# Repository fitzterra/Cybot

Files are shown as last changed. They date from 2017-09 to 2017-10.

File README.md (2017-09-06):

Cybot Resurrected
=================

**Table of Contents**
1. [Features](#features)
2. [Hardware and Electronics](#hardware-and-electronics)
3. [Software](#software)

----

This is a project to bring my old [Cybot] back my to life.

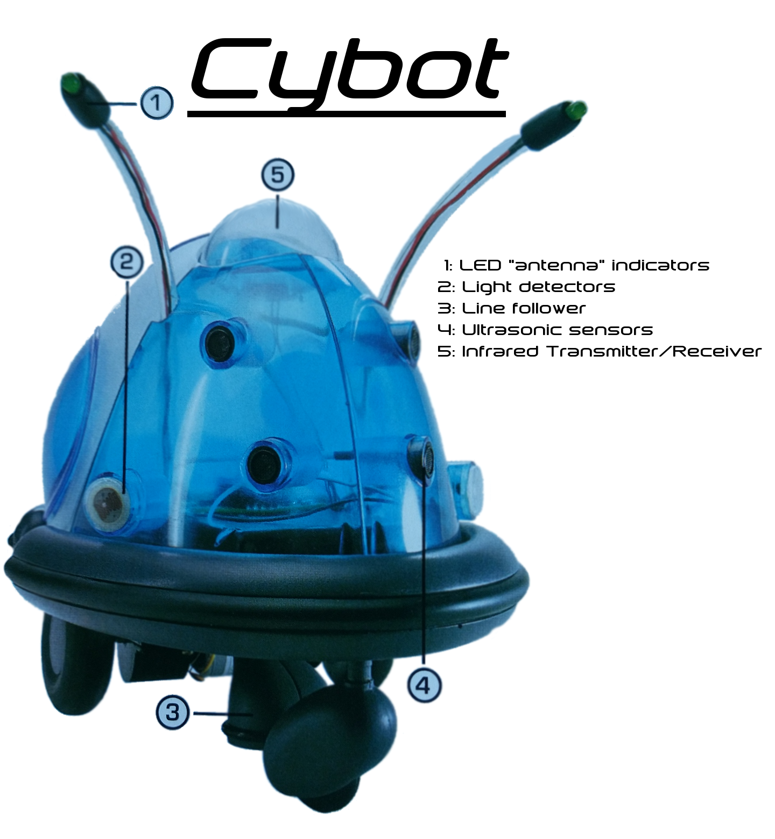
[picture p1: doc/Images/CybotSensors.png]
Cybot Sensors

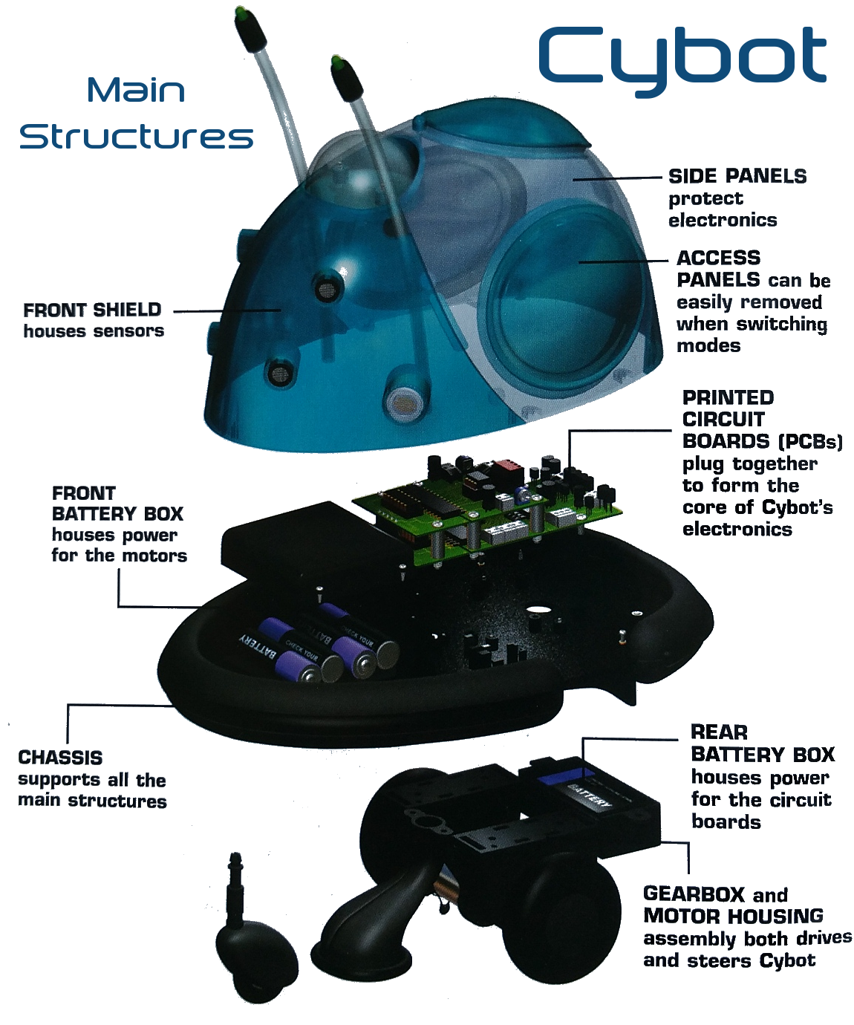
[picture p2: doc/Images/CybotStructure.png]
Cybot Structure


After I lost my remote control (it was stolen actually, by some idiot who
probably thought it was a game controller :angry: ), Cybot has just been sitting
there for quite a number of years.

A while back I built [FoamBot] which was a robot in which I used [Foam Board]
exclusively as construction material, continues servos as drive train, and an
Arduino Uno as MCU. The software for [FoamBot] was based on a simple
[co-operative multitasking] library, with all functionality built as (almost)
completely independent tasks to form a very loosely defined type of Robot
Operating System.

Due to time constraints and some waning of interest, FoamBot took a backseat.
When I now recently got the urge to build a remote controller robot again, I
decided to use as much of Cybot as possible, but replace the MCU with something
Arduino based. This is where we now begin :smile:.

Features
--------
This list will be expanded as more things are added, at a minimum, these are the
features I would like for now:

* Use as much of the Cybot sensors and hardware as possible
* Controlled via:
    - Direct serial connection - this will be more for testing and debugging,
      and will be a tethered connection.
    - Infrared - this will obviously be a remote control, it should use the
      original Cybot IR Receiver, and should be able to use any available IR
      remote (after training Cybot for the remote - see below)
    - Bluetooth - also a remote control. This will allow many mobile apps to act
      as a remote control, and will allow things like using a phone's gyro,
      accelerometer and other sensors to control the bot by simply tilting and
      moving the phone in the air.
* All input controls should have the options to be trainable in order to ensure
  the controller can issue the correct robot control commands. Trained control
  mappings should be stored in EEPROM to survive power offs.
* Obstacle avoidance using light sensors and/or ultrasonic and/or IR (using a
  separate IR sensor).
* Line follower option.

Hardware and Electronics
------------------------
ToDo

Software
--------
See [here](firmware) for details about the Robot Control software.

[Cybot]: https://en.wikipedia.org/wiki/Real_Robots
[FoamBot]: https://github.com/fitzterra/FoamBot
[Foam Board]: https://en.wikipedia.org/wiki/Foamcore
[co-operative multitasking]: https://github.com/fitzterra/Task
[firmware]: firmware/README.md

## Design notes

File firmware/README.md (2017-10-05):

Software for Robot Control
==========================

**Table of Contents**
1. [Abstract](#abstract)
2. [Development Environment](#development-environment)
3. [Required external libraries](#required-external-libraries)
	1. [Streaming](#streaming)
	2. [Task](#task)
	3. [IRRemote](#irremote)
	4. [SoftPWM](#softpwm)
4. [Components](#components)
	1. [Configuration](#configuration)
	2. [Debugging](#debugging)
	3. [Utils](#utils)
	4. [Input Control and Robot commands](#input-control-and-robot-commands)
	5. [Drive Train and Wheels](#drive-train-and-wheels)
5. [Testing](#testing)

Abstract
--------
This is the code base for Cybot's software.

It is written for an Arduino type environment, although the Arduino IDE and
compiler is not used, and may even break if trying to compile and upload the
code as is - I have not tested, sorry :grimacing:

Development Environment
-----------------------
I can not stand the clunky Arduino IDE and prefer to use my editor of choice
which is Vim (or gVim actually) - I can not imagine using any other editor
:smile:

Although the Arduino IDE allows an external editor but still compile and upload
via the IDE, I prefer to compile/upload from the terminal or directly from
within Vim. I can even start a serial terminal from within Vim :satisfied:

Also note that I develop on Linux exclusively, so have no idea how feasible this
environment is on other platforms.

I use Sudar Muthu's [Arduino-Makefile] to build and upload to the Arduino. This
`Makefile` still needs the Arduino IDE and code base to be installed, and
requires a path to where it is installed to be hardcoded in the Makefile.

In addition to the path to the Arduino files, it also needs paths to some other
things like the original installation dir for [Arduino-Makefile], your local
Arduino libraries dir, etc.

These are currently hardcoded to where they live in my environment, so should be
changed to your environment should you try to use the `Makefile`.

Required external libraries
---------------------------
This code requires the following external libraries to be installed:

### Streaming
A very useful extension to streams that overloads the `<<` operator and allows
things like:
```
Serial << "One apple + one pear = " << (1+1) << " fruit." << endl;
```

Instead of the clunky:
```c++
Serial.print("One apple + one pear = ");
Serial.print(1+1);
Serial.println(" fruit.");
```

**Installation**: Get the library from **Mikal Harts's** site
[here][streaminglib] and install in your `libraries` directory. This has to be
done manually since it is not available via the built in Arduino library manager
as of this writing.

### Task
This is a very simple [task manager] for co-operative multitasking by **Alan
Burlison**. It allows for each sensor, motors, input control, etc. to be written
as small fast executing tasks, all independent of each other. The task manager
will then execute each of these task whenever it needs executing.

This helps decoupling the various components from each other and makes it much
easier to write and manage the control code.

**Installation**: One of these options:
* Download the tarball directly from [Alans's site][task manager] and install in
  your `libraries` directory
* If cloning a GitHub repo is easier, you can clone my [GitHub wrapper][githubTaskLib]
  for Alan's Task library in your `libraries` directory

### IRRemote
This is only needed if Infrared remote control will be used. See
[configuration](#configuration) for more details on enabling IR remote
functionality.

**Installation**: This can be installed vi the Arduino IDE Library Manager.
Search for `IRRemote` by **shirrif**.

### SoftPWM
This library provides software PWM which allows any digital pin to be used for
PWM control and not only yhe hardware PWM pins.

Configuring software PWM for speed control can be done my defining
`HBRIDGE_SOFT_PWM` in `config.h` under the *HBRIDGE_DRV_EN* section.

This should only be done if it is not possible to use have 4 hardware enabled
PWM pins for controlling the two HBridges. Software PWM is slower than hardware
PWM and also has some other limitations that might become an issue depending on
the complexity and other libraries used in the rest of the control system.

**Installation**: Clone it from **Brett Hagman's** [SoftPWM GitHub] repo into
your `libraries` directory.

### ACROBOTIC SSD1306
This library is used for SSD1306 type OLED display that is currently supported.
It is only needed if the display will be used.

The display currently supported is a 128x64 OLED, driven by the SSD1306 chip
over I2C.

**Installation**:  This can be installed via the Arduino IDE Library Manager.
Search for `ACROBOTIC SSD1306` by **ACROBOTIC**.

Components
----------
The software consists of the following components:

### Configuration
The configuration file, **`config.h`** is used to configure all components,
hardware, optional items and everything else.

All configuration option in this file is well documented, so please read there
for details.

### Debugging
The **`debug.h`** file includes a macro that can be used to easily generate
debug output. The macro is defined to output the supplied arguments to the
serial port if `_DEBUG` is defined in `config.h`.

If `_DEBUG` is not defined, the macro has an empty definition, and does not do
anything when called.

_**ToDo**_: Optionally allow debug output via Bluetooth or even onboard display
in future.

### Utils
These files (`utils.h` and `utils.cpp`) are for general small utility functions
that do not justify their own full source files.

### Input Control and Robot commands
This component is responsible for reading various input controllers (serial, IR,
Bluetooth, etc.) and decoding this input to robot control commands.

See the [controls] documentation for more details.

### Drive Train and Wheels
A **Wheel** is modeled as an object that can be rotate forwards or backwards at a
set _speed_. The _speed_ is not a distance over time like meters/second for
example, but rather a percentage of the full power of the motor.

This means that a speed value of `50` will rotate the wheel at 50% of it's full
power. The speed can be in the range `-100` (full speed backwards) to `100`
(full speed forwards).

For Continues Rotation Servos, the _power_ is managed by setting the servo
angle, which makes the servo rotate slower or faster to try to reach the angle.
For HBridges with Brushed DC Motors, the _power_ is managed via PWM.

A **Drive Train** is modeled as two wheels of the same type, placed on the left
and right sides of the chassis. The drive train can then be told to drive at a
specific speed (again, as a percentage of full rotation speed of the wheels),
forwards or backwards, or to change to a set direction.

As for the speed value, the _direction_ value is also a percentage between
`-100` and `100`. For direction, a value of `0` means straight forward which will
turn both wheels in the same direction at the same _speed_. Directions between
`0` and `100` will make the robot turn to the left, with `50` representing the
`90°` point (east). With a direction of `50`, the right wheel is stopped while
the left wheel turns at the current _speed_.

The direction `100` represents `180°`, in which case the right wheel is turning
in _reverse_ at the current _speed_, while the left is going forward at the
current _speed_. This means the robot is spinning clockwise on the same spot.

The directions from `0` to `-100` are for turning in the left (west) direction,
with the behaviour exactly the same as for the right direction.

Note that `100` and `-100` are both `180°` spinning around the central axis,
except that the direction of spin is different.

This diagram explains the relationship between _speed_, _direction_ and the
actual wheel turning speed:

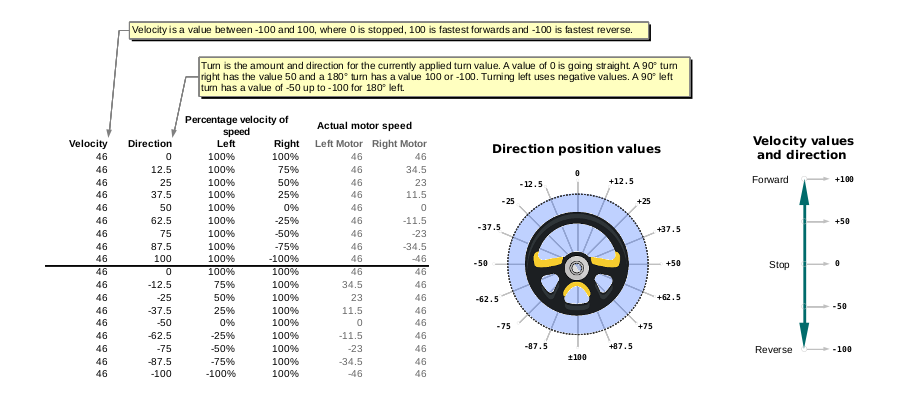
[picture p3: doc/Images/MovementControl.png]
Movement Control


Testing
-------
See the [testing] documentation for more details

[Vim]: http://vim.org
[Arduino-Makefile]: https://github.com/sudar/Arduino-Makefile
[streaminglib]:  http://arduiniana.org/libraries/streaming/
[task manager]: http://bleaklow.com/2010/07/20/a_very_simple_arduino_task_manager.html
[githubTaskLib]: https://github.com/fitzterra/Task
[SoftPWM GitHub]: https://github.com/bhagman/SoftPWM
[controls]: ControlCommand.md
[testing]: tests/README.md

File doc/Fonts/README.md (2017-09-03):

Free Fonts Used
===============

The original Cybot print copy had a specific font that they used for the Cybot
name and also some other bits in the magazines.

I wanted to keep this look as close as possible, so found this Freeware font
called _Downlink_ distributed by [Pixel Sagas]. The font and it's license
agreement is contained in the `downlink.zip` ZIP file.

----
[Pixel Sagas]: http://www.pixelsagas.com/

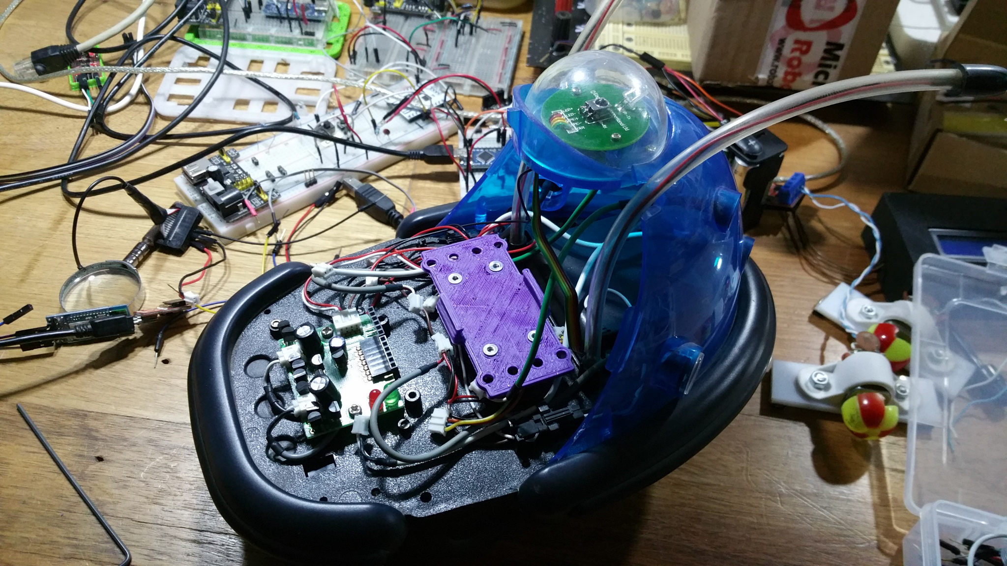
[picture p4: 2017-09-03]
doc/Images/MountMCUBracket-2.jpg

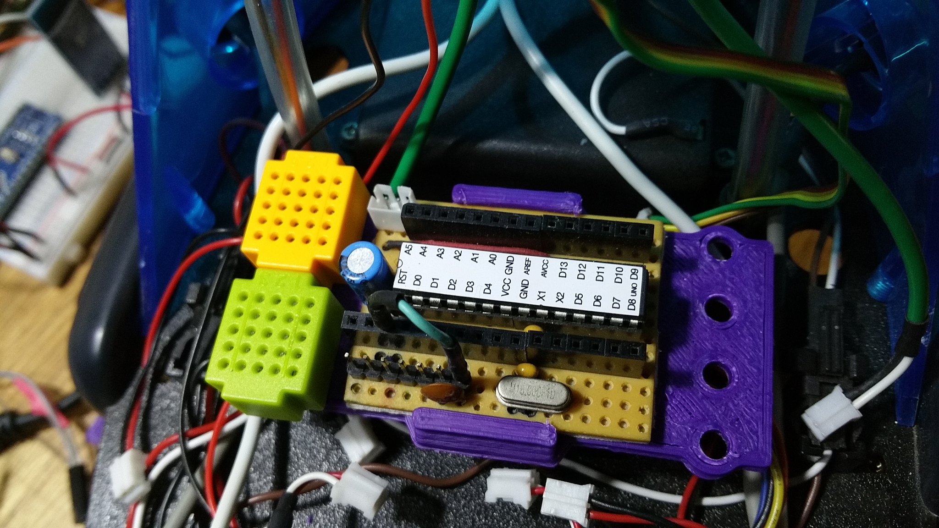
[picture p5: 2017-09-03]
doc/Images/MountArduino-2.jpg

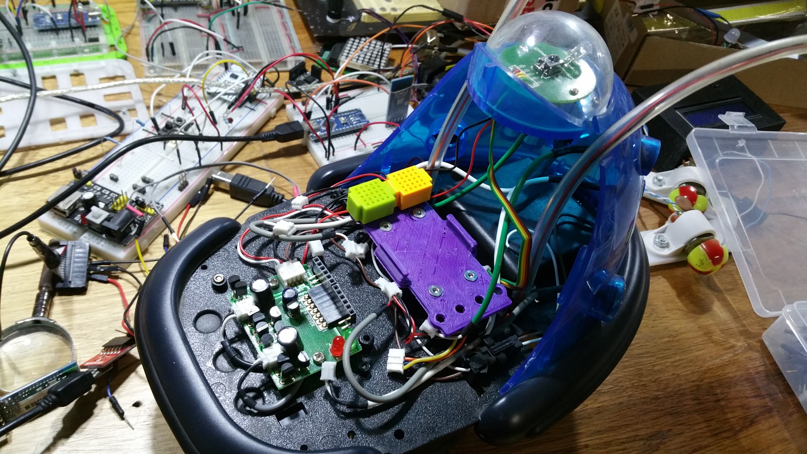
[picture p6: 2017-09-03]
doc/Images/MiniBreadboardLeft.jpg

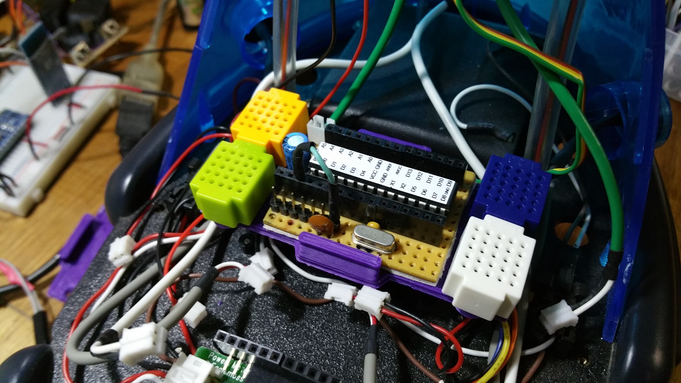
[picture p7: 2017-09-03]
doc/Images/MountedMCUandBreadboard.jpg

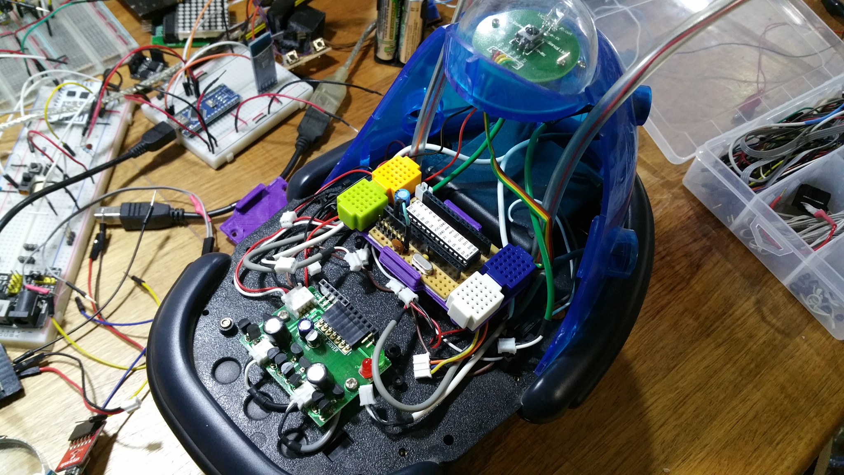
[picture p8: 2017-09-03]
doc/Images/MiniBreadboardRight.jpg

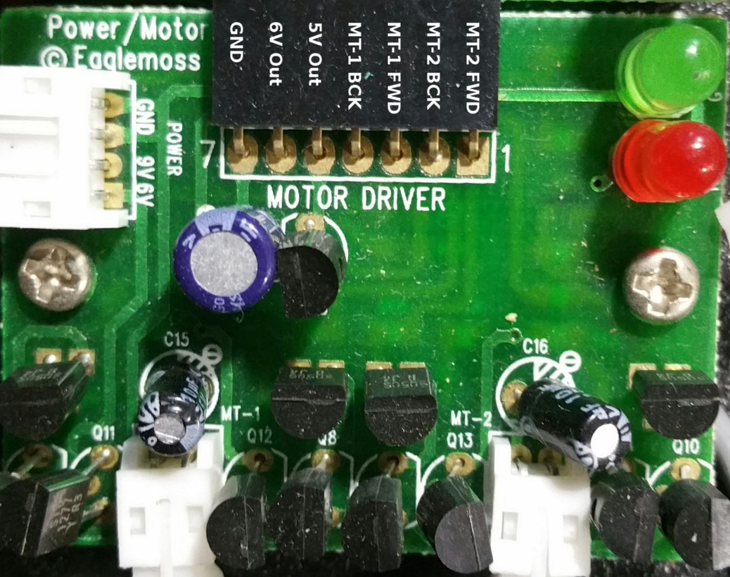
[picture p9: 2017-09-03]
doc/Images/MotorDriver.png

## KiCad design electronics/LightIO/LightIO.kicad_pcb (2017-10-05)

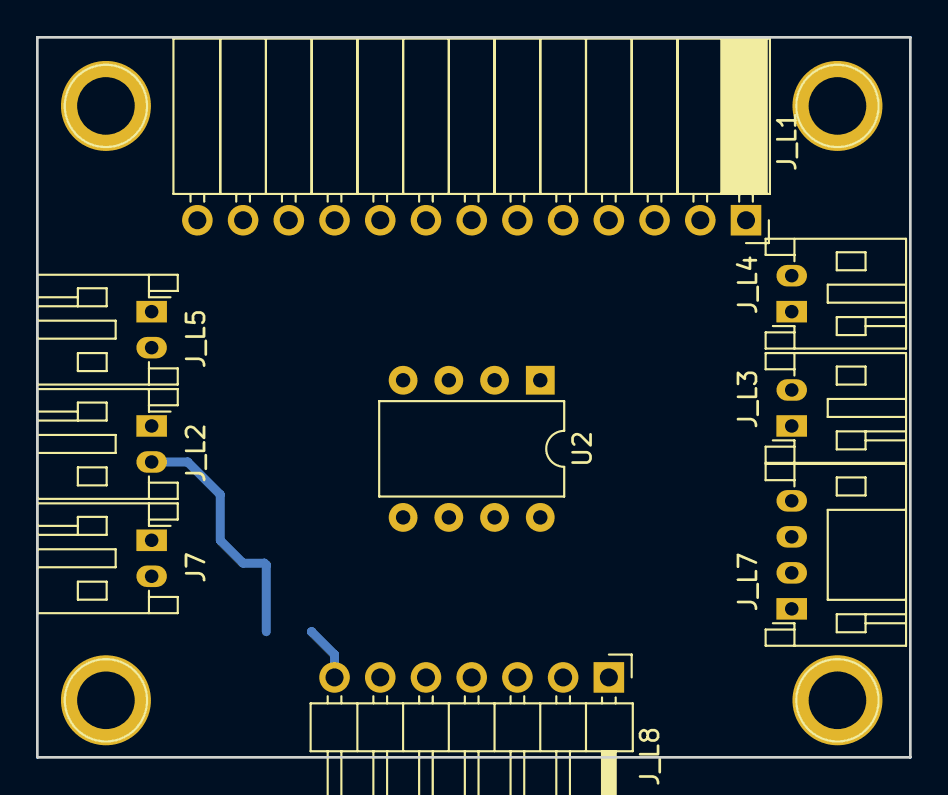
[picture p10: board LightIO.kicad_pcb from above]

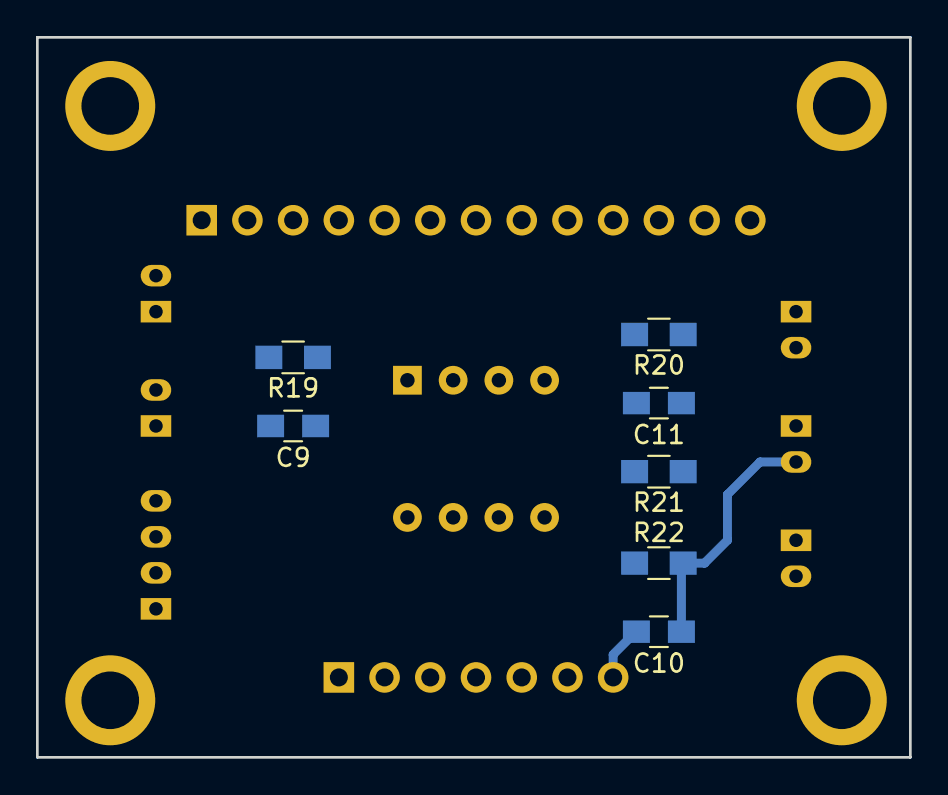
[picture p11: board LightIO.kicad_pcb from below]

Board: 2 copper layers, 48.5 x 40.0 mm, 16 parts (7 on the bottom side), 19 nets.

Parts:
C9, C10, C11: 100nF; C_0805_HandSoldering
J7: Piezo; JST_PH_S2B-PH-K_02x2.00mm_Angled
J_L1: LightProcPCB; Socket_Strip_Angled_1x13_Pitch2.54mm
J_L2: CDS-L; JST_PH_S2B-PH-K_02x2.00mm_Angled
J_L3: CDS-R; JST_PH_S2B-PH-K_02x2.00mm_Angled
J_L4: LED-R; JST_PH_S2B-PH-K_02x2.00mm_Angled
J_L5: LED-L; JST_PH_S2B-PH-K_02x2.00mm_Angled
J_L7: Line; JST_PH_S4B-PH-K_04x2.00mm_Angled
J_L8: Motor PCB; Pin_Header_Angled_1x07_Pitch2.54mm
R19: 47k; R_0805_HandSoldering
R20: 62; R_0805_HandSoldering
R21, R22: 300; R_0805_HandSoldering
U2: LM311; DIP-8_W7.62mm

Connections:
/+5V: C9.1, J_L1.11, J_L2.1, J_L3.1, J_L7.4, J_L8.5, R19.2, U2.8
/+6V: J_L1.12, J_L8.6, R20.2
/AntLED: J_L1.6, J_L4.2
/BZ+: J7.1, J_L1.2
/BZ-: J7.2, J_L1.3
/CDS-L: J_L1.4, R22.1
/CDS-R: J_L1.5, R21.2
/LnFol: J_L1.1, R19.1, U2.7
/M1A: J_L1.9, J_L8.3
/M1B: J_L1.10, J_L8.4
/M2A: J_L1.7, J_L8.1
/M2B: J_L1.8, J_L8.2
GND: C9.2, C10.2, C11.2, J_L1.13, J_L7.1, J_L8.7, U2.1, U2.4
unnamed: C10.1, J_L2.2, R22.2
unnamed: C11.1, J_L3.2, R21.1
unnamed: J_L4.1, J_L5.2
unnamed: J_L5.1, R20.1
unnamed: J_L7.2, U2.3
unnamed: J_L7.3, U2.2

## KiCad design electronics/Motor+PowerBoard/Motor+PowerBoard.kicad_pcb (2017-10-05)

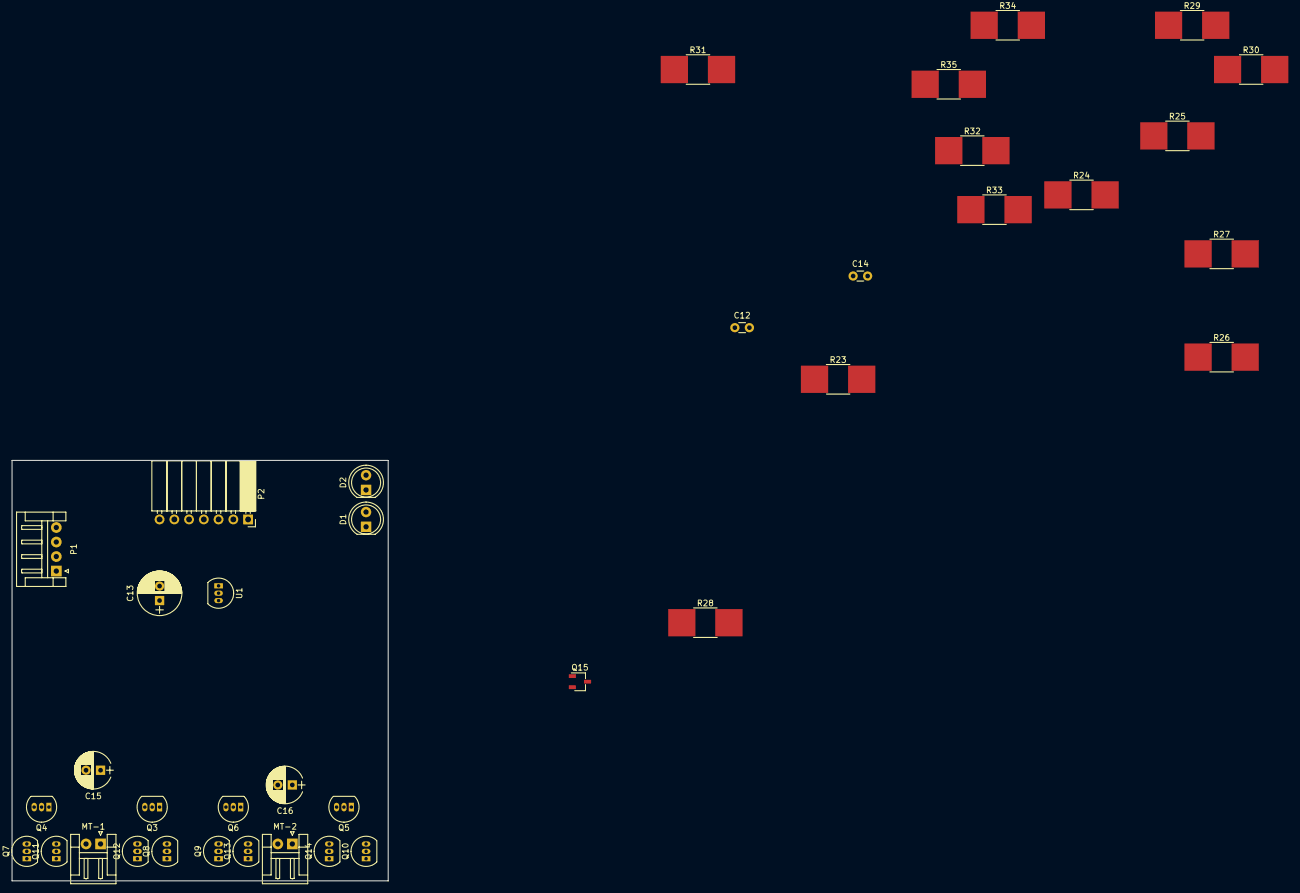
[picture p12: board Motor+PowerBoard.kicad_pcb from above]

Board: 2 copper layers, 64.8 x 72.4 mm, 38 parts (0 on the bottom side), 32 nets, no tracks yet.

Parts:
C12, C14: 100nF; C_Disc_D3.0mm_W1.6mm_P2.50mm
C13: 220uF; CP_Radial_D7.5mm_P2.50mm
C15, C16: 10uF; CP_Radial_D6.3mm_P2.50mm
D1: Red; LED_D5.0mm
D2: Green; LED_D5.0mm
MT-1, MT-2: JSTx2; JST_EH_S02B-EH_02x2.50mm_Angled
P1: Power; JST_EH_S04B-EH_04x2.50mm_Angled
P2: Connect; Socket_Strip_Angled_1x07_Pitch2.54mm
Q3, Q4, Q5, Q6: S8050; TO-92_Inline_Narrow_Oval
Q7, Q8, Q9, Q10: 2SC3279; TO-92_Inline_Narrow_Oval
Q11, Q12, Q13, Q14: 2SA1300; TO-92_Inline_Narrow_Oval
Q15: NPN SMD; TSOT-23
R23: 10; R_2816_HandSoldering
R24, R25: 2k7; R_2816_HandSoldering
R26: 10k; R_2816_HandSoldering
R27: 1k2; R_2816_HandSoldering
R28, R29, R30, R31: 1k; R_2816_HandSoldering
R32, R33, R34, R35: 100; R_2816_HandSoldering
U1: LM78L05_TO92; TO-92_Inline_Narrow_Oval

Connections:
+6V: C12.1, P2.6, Q11.1, Q12.1, Q13.1, Q14.1
+9V: R23.2, R24.2, R25.2, R26.2
/+5V: C14.1, P2.5, U1.1
/M1A: P2.3, R29.1
/M1B: P2.4, R28.1
/M2A: P2.1, R30.1
/M2B: P2.2, R31.1
GND: C12.2, C13.2, C14.2, D1.1, D2.1, P2.7, Q7.1, Q8.1, Q9.1, Q10.1, Q15.3, R27.1, U1.2
unnamed: C13.1, R23.1, U1.3
unnamed: C15.1, Q7.2, Q11.2
unnamed: C15.2, Q8.2, Q12.2
unnamed: C16.1, Q9.2, Q13.2
unnamed: C16.2, Q10.2, Q14.2
unnamed: D1.2, Q15.2, R25.1
unnamed: D2.2, R24.1
unnamed: Q3.1, Q8.3
unnamed: Q3.2, R28.2
unnamed: Q3.3, R33.2
unnamed: Q4.1, Q7.3
unnamed: Q4.2, R29.2
unnamed: Q4.3, R32.2
unnamed: Q5.2, R31.2
unnamed: Q5.3, R34.2
unnamed: Q6.1, Q9.3
unnamed: Q6.2, R30.2
unnamed: Q6.3, R35.2
unnamed: Q5.1, Q10.3
unnamed: Q11.3, R33.1
unnamed: Q12.3, R32.1
unnamed: Q13.3, R34.1
unnamed: Q14.3, R35.1
unnamed: Q15.1, R26.1, R27.2

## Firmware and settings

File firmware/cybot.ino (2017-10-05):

/**
 * Cybot Resurrected.
 *
 **/

#include "config.h"
#include "debug.h"
#include "control.h"
#include "driveTrain.h"

// Set up pointer for each enabled input method.
#ifdef INP_SERIAL_EN
SerialIn *sInput;
#endif // INP_SERIAL_EN
#ifdef INP_BT_EN
BTIn *btInput;
#endif // INP_BT_EN
#ifdef INP_IR_EN
IRIn *irInput;
#endif // INP_IR_EN

// Display pointer
#ifdef DISPLAY_EN
#include "display.h"
Display *display;
#endif // DISPLAY_EN

// The drive train object pointer
DriveTrain *drvTrn;

// Function to initialize the shared space to default values where required.
// For some reason the members can not be initialized individually outside of a
// function at this level - not sure why that is.
void initShared() {
    shared.nxtCmd = CMD_ZZZ;
    shared.speed = 0;
    shared.dir = 0;
}

void setup() {
    initShared();

    OpenSerial();
    D(F("Starting...\n"));

    // Load command maps from EEPROM
    loadCmdMaps();

    // Create required input method instances
#ifdef INP_SERIAL_EN
    sInput = new SerialIn(commandMaps.serialMap, &shared.nxtCmd,
                          SI_MIN_DELAY, SI_REPEAT_MAX);
#endif // INP_SERIAL_EN
#ifdef INP_BT_EN
    btInput = new BTIn(commandMaps.btMap, &shared.nxtCmd,
                       BT_MIN_DELAY, BT_REPEAT_MAX);
#endif // INP_BT_EN
#ifdef INP_IR_EN
    irInput = new IRIn(IR_PIN, commandMaps.irMap, &shared.nxtCmd,
                       IR_MIN_DELAY, IR_REPEAT_MAX);
#endif // INP_IR_EN
#ifdef DISPLAY_EN
    display = new Display(DISP_UPD_FREQ);
#endif // DISPLAY_EN

    // Create the drive train object based on the selected drive option
#ifdef HBRIDGE_DRV_EN
    drvTrn = new DriveTrain(&shared.nxtCmd, HBRIDGE_LEFT_FWD, HBRIDGE_LEFT_REV,
                            HBRIDGE_RIGHT_FWD, HBRIDGE_RIGHT_REV);
#else
    drvTrn = new DriveTrain(&shared.nxtCmd, SERVO_LEFT, SERVO_RIGHT);
#endif // HBRIDGE_DRV_EN
}

void loop() {
    // Set up the tasks
    Task *tasks[] = {
#ifdef INP_SERIAL_EN
            sInput,
#endif // INP_SERIAL_EN
#ifdef INP_BT_EN
            btInput,
#endif // INP_BT_EN
#ifdef INP_IR_EN
            irInput,
#endif // INP_IR_EN
#ifdef DISPLAY_EN
            display,
#endif // DISPLAY_EN
            drvTrn,
        };

    // The scheduler
    TaskScheduler sched(tasks, NUM_TASKS(tasks));

    // and go...
    sched.run();
}

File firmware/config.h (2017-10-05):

/**
 * Application compile time config settings.
 */

#ifndef _CONFIG_H_
#define _CONFIG_H_

#include <stdint.h>
#include "sharedSpace.h"

// Define this to enable debugging
#define _DEBUG

// The speed for the serial port for debug output and also for the serial input
// handler if enabled.
#define SERIAL_SPEED 115200
// If using a Bluetooth input or output, these are the TX and RX pins for the
// Software Serial connection to the BT module and also the speed.
#define SOFTSERIAL_RX 12
#define SOFTSERIAL_TX 11
#define SOFTSERIAL_SPEED 9600
// If SOFTSERIAL_EN is defined, the config mechanism will make a globally
// accessible software serial port available called SSerial which will behave
// the same as the standard Serial port.
// If enabling Bluetooth input below (INP_BT_EN), SOFTSERIAL_EN would
// automatically be defined since the BT input mechanism depends on SSerial.
// Define this to create the SSerial port - see also OpenSoftSerial in utils.
//#define SOFTSERIAL_EN

// When in learn mode, how long to wait for input before timing out and exiting
// learn mode without saving the learned input. The value is in milliseconds
#define LEARNMODE_TIMEOUT 10*1000;

// Define this if you want to get feedback on current speed and direction over
// the Bluetooh software serial port.
#define BT_FEEDBACK


// @@@@@@@@@@@@ Feature selection definitions @@@@@@@@@@@@@@@
//
// Comment the #defines out to disable the feature, leave it uncommented to
// enable the feature. Each feature will have it's own config section below, so
// remember to also configure the feature there if it has been enabled.
//
// ~~~~~~ Control input options ~~~~~~~~
// These can all be available as long as the hardware does not conflict
// NOTE! Any changes here will mean the EEPROM signature needs to be changed -
//       see commandMaps.eepromSig in commands.cpp
#define INP_SERIAL_EN   // Enables serial input control
#define INP_IR_EN       // Enables Infrared input control
#define INP_BT_EN       // Enables Bluetooth Serial input Control
//
// ~~~~~~ Wheel driver options ~~~~~~~
// Continues rotation servos or HBridge (Left/Right Forward/Reverse) wheel
// control are supported. Only enable one of the two options, then configure the
// selection option below.
//
//#define SERVO_DRV_EN  // Needs one digital pin for each wheel
#define HBRIDGE_DRV_EN  // Needs 2 digital pins per wheel
// ~~~~~~ Sensor options ~~~~~~~
//#define LINEFOL_EN      // Enables the line follower feature
//#define BUMPERS_EN      // Enables bumper switches
// ~~~~~~ Display options ~~~~~~~
//#define LCD_EN           // Enable Nokia mono LCD (PDC8544)
#define OLED_EN          // Enable OLED display

// Auto define DISPLAY_EN if eithe LCD or OLED is enable
#if defined(LCD_EN) || defined(OLED_EN)
    #define DISPLAY_EN
#endif
// @@@@@@@@@@@@@@@@@@@@@@@@@@@@@@@@@@@@@@@@@@@@@@@@@@@@@@@@@@@


// Sanity check at compile time to ensure only one of servo or hbridge control
// is enabled
#if defined(SERVO_DRV_EN) && defined(HBRIDGE_DRV_EN)
#error "You should only define SERVO_DRV_EN or HBRIDGE_DRV_EN, not both!"
#endif
// And that at least on input method has been defined
#if !(defined(INP_SERIAL_EN) || defined(INP_IR_EN) || defined(INP_BT_EN))
#error "You have not defined any input method. At least one of INP_???_EN defines are needed."
#endif

// We do not support LCD yet, so error out if enabled
#ifdef LCD_EN
#error "The LCD display is not supported yet. Only OLED for now."
#endif

// ############### General utility definitions #################
// NOTE!!! DO NOT change the values of these defs - LEFT and RIGHT are used as
// array indexes and should always be values 0 and 1
enum { LEFT=0, RIGHT=1, FORWARD=2, BACKWARD=3, STOP=4 };

// ############### Serial Input config #################
#ifdef INP_SERIAL_EN
// This is the minimum delay required between successive serial input characters.
// If successive input is received within this delay period, the input will be
// read from the serial line, but it will be discarded. Note that keystrokes that
// deliver multiple characters like CRLF for Enter will only ever show the first
// character.
// The reason for this delay is to prevent overenthusiastic pressing of keys to
// send the same command to a robot. Many robot commands takes a short while
// before the results can be seen.
#define SI_MIN_DELAY 100
// Some commands will behave differently depending on whether the command is being
// repeated or just sent in quick succession. This value determines the max time
// interval between successive receipt of the same character which would count as
// a repeat of this input.
#define SI_REPEAT_MAX 250
#endif // INP_SERIAL_EN

// ############### IR Input config #################
// ??? Uses the IRremote library ????
#ifdef INP_IR_EN
// IR Receiver pin
#define IR_PIN  2
// As for SI_MIN_DELAY, but only for IR
#define IR_MIN_DELAY 100
// As for SI_REPEAT_MAX, but only for IR
#define IR_REPEAT_MAX 250
#endif // INP_IR_EN
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

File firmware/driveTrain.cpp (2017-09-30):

/**
 * Objects for controlling drive train.
 **/

#include "driveTrain.h"

// ####################### PWM handling Abstraction ######################

/**
 * Function to set a pin up for PWM control.
 *
 * This function is an abstraction for hardware and software PWM control. It
 * provides a single interface for setting up a pin for either hardware or
 * software PWM, for use with an HBridge driver module.
 *
 * The complementary function to this one, PWMSetValue(), is an abstration for
 * setting a PWM value on a PWM pin.
 *
 * Whether hardware or software PWM is in affect, will be determined by the
 * HBRIDGE_SOFT_PWM define set up in `config.h`.
 *
 * If HBRIDGE_SOFT_PWM is defined, then software PWM will be used via the
 * SoftPWM library by Brett Hagman. This library is available via the normal
 * Arduino library manager.
 *
 * This function should be called to set up a specific pin for PWM control and
 * does the following for:
 *
 *   * Hardware PWM:
 *     - Simply set the pin as output
 *
 *   * Software PWM:
 *     - Call the SoftPWMBegin() if it has not already been called. Internally
 *       it will ensure this only gets called once irrespective of how many
 *       software PWM pins are being set up.
 *     - Set the fade up and down times for the pin to 0 to ensure instant PWM
 *       changes when setting a new PWM value. See the SoftPWMSetFadeTime()
 *       function documentation.
 *
 * @param pin: The pin to set up for PWM.
 **/
void PWMSetupPin(uint8_t pin) {
#ifdef HBRIDGE_SOFT_PWM
    // Indicates if SoftPWMBegin has been called yet
    static bool initialized = false;

    // Initialize SoftPWM if not done yet
    if(!initialized) {
        SoftPWMBegin();
        initialized = true;
    }

    SoftPWMSet(pin, 0);

    // Zero fade times for the pin
    // This is important to ensure that a pin goes to 0 immediatly to avoid
    // having both HBridge pins high at any give ntime.
    SoftPWMSetFadeTime(pin, 0, 0);
#else
    // For hardware PWM, we simply set the pin to output
    pinMode(pin, OUTPUT);
#endif // HBRIDGE_SOFT_PWM
}

/**
 * PWM pin value change abstraction function.
 *
 * This function abstracts setting a pin to a given PWM output value for
 * hardware and software PWM control.
 *
 * It is a complimentary function to PWMSetupPin(). Please see PWMSetupPin()
 * for more details.
 *
 * This function should be called to set the PWM output for a pin which was
 * previously set up via PWMSetupPin()
 *
 * @param pin: The pin to set the value for.
 * @param percent: a value between 0 and 100 as a percentage of pulse width
 *        to set, with 0 being full off and 100 being full on.
 */
void PWMSetValue(uint8_t pin, uint8_t percent) {
#ifdef HBRIDGE_SOFT_PWM
    // For SoftPWM we can pass the percentage directly
    SoftPWMSetPercent(pin, percent);
    //SoftPWMSet(pin, map(percent, 0, 100, 0, 255));
#else
    // For hardware PWM we need to map the percentage value to valid PWM values
    // between 0 and 255
    analogWrite(pin, map(percent, 0, 100, 0, 255));
#endif
}

// ####################### Wheel class definitions ######################

#ifdef SERVO_DRV_EN
/**
 * Continues Rotation Servo wheel constructor
 *
 * @param p: The pin the servo is connected to.
 * @param sd: The side (LEFT or RIGHT) the wheel is attached to.
 * @param inv: Optional boolean to invert the direction of rotation.
 **/
Wheel_CRS::Wheel_CRS(uint8_t p, int8_t sd, bool inv) :
    Wheel(sd, inv), pin(p) {

    // Attach the servo to the pin
    servo.attach(pin);
    // Set to stationary
    setSpeed(0);
}

/**
 * Sets the wheel speed for Continues Rotation Servo
 *
 * @param sp: The rotation speed: -100% to 100% with positive as forward speed
 *        and negative as reverse speed. A speed of 0 is stop.
 */
void Wheel_CRS::setSpeed(int8_t sp) {
    uint8_t angle;

    // Validate the speed
    if (!validSpeed(sp))
        return;

    // Save the speed
    speed = sp;

    // Map the speed value between -100 (full speed reverse) and 100 (full speed
    // ahead) to an angle between 0 (full speed rotate left) to 180 (full speed
	// rotate right). Reverse the angle for a wheel with inverted direction.
    if (!inverted) {
        angle = map(speed, -100, 100, 0, 180);
    } else {
        angle = map(speed, 100, -100, 0, 180);
    }

    // Set the speed and direction
    servo.write(angle);
    // Debug output
    D(F("Setting ") << side << F(" angle to ") << angle << F(" for speed ") \
        << speed << endl);
}
#endif // SERVO_DRV_EN

#ifdef HBRIDGE_DRV_EN
/**
 * HBridge motor driver wheel constructor
 *
 * @param pinF: The pin for forward rotation
 * @param pinR: The pin for reverse rotation
 * @param sd: The side (LEFT or RIGHT) the wheel is attached to.
 * @param inv: Optional boolean to invert the direction of rotation.
 **/
Wheel_HB::Wheel_HB(uint8_t pinF, uint8_t pinR, int8_t sd, bool inv) :
    Wheel(sd, inv), pinFwd(pinF), pinRev(pinR) {

    // Set the pins up for PWM
    PWMSetupPin(pinFwd);
    PWMSetupPin(pinRev);

    // Set to stationary
    setSpeed(0);
}

/**
 * Sets the wheel speed for HBridge motor driver
 *
 * @param sp: The rotation speed: -100% to 100% with positive as forward speed
 *        and negative as reverse speed. A speed of 0 is stop.
 */
void Wheel_HB::setSpeed(int8_t sp) {
    // Validate the speed
    if (!validSpeed(sp))
        return;

    // Save the speed
    speed = sp;

    // One of the pins needs to turned off (set to zero) depending on the
    // direction and inverted settings
    uint8_t zeroPin = speed<0 ? pinFwd : pinRev;
    // The other pin will be the control pin
    uint8_t ctrlPin = speed<0 ? pinRev : pinFwd;
    // Invert the direction if required.
    if(inverted) {
        uint8_t tmp = zeroPin;
        zeroPin = ctrlPin;
        ctrlPin = tmp;
    }

    // Set the pins, making sure to ALWAYS set the zero pin first to make
    // *SURE* we never have a situation where both forward and reverse pins are
    // high, which would destroy the H-Bridge!
    PWMSetValue(zeroPin, 0);
    // Now we can set the PWM duty cycle on the control pin
    PWMSetValue(ctrlPin, abs(speed));
    D(F("Setting ") << side << F(" side pin ") << zeroPin << F(" to off and pin ") \
            << ctrlPin << F(" to ") << abs(speed) << endl);
}
#endif // HBRIDGE_DRV_EN

// ####################### DriveTrain class definitions ######################

/**
 * Contstructor
 **/
#ifdef HBRIDGE_DRV_EN
DriveTrain::DriveTrain(uint8_t *cs, uint8_t pinLeftF, uint8_t pinLeftR,
                       uint8_t pinRightF, uint8_t pinRightR,
                       bool leftInv, bool rightInv) {
    // Save pointer to command store
    commandStore = cs;
    // Create wheel instances
    wheel[LEFT] = new Wheel_HB(pinLeftF, pinLeftR, LEFT, leftInv);
    wheel[RIGHT] = new Wheel_HB(pinRightF, pinRightR, RIGHT, rightInv);
	// Default speed and direction to 0
	speed = dir = 0;
    // Zero power start timer
    powerStartTimer = 0;
};
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

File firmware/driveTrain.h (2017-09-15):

/**
 * Objects for controlling drive train.
 **/


#ifndef _DRIVETRAIN_H_
#define _DRIVETRAIN_H_

#include "config.h"
#include "debug.h"
#include "commands.h"
#include <Task.h>
#include <Arduino.h>
#ifdef SERVO_DRV_EN
#include <Servo.h>
#endif // SERVO_DRV_EN
#ifdef HBRIDGE_SOFT_PWM
#include <SoftPWM.h>
#endif // HBRIDGE_SOFT_PWM


#define SPEED_STEP 5    // Increments for speed changes 
#define TURN_STEP 5     // Increments for turning left or right
#define MAX_LEFT -100   // Max value for the left direction
#define MAX_RIGHT 100   // Max value for the right direction
#define MAX_SPEED 100   // Max speed value
#define MIN_SPEED -100  // Min speed value

// #### PWM Hardware/Software Abstraction functions ####
void PWMSetupPin(uint8_t pin);
void PWMSetValue(uint8_t pin, uint8_t percent);

/**
 * Abstract base class for controlling a wheel.
 *
 * This class is only concerned about rotating the wheel forward or backwards
 * at a given percentage of full speed, with a speed of 0 indicating stop.
 *
 * The details on how the wheel speed and direction is controlled needs to be
 * implemented in subclasses of this base class for the specific type rotation
 * device for example a brushed DC motor (BDM), continues rotation servo
 * (CRS), etc.
 **/
class Wheel {
    protected:
        // The side of the robot the wheel is attached to. Either LEFT (0) or RIGHT (1)
        uint8_t side;
        // The current speed of the wheel as a percentage between -100% (full
        // speed reverse) and 100% (full speed forward)
        int8_t speed;
        // Whether to invert the rotation direction
        bool inverted;

    public:
        Wheel(uint8_t sd, bool inv=false) : 
            side(sd), inverted(inv) {};
        // Utility method to test if the speed is in the valid range
        bool validSpeed(int8_t speed) { return (speed>=MIN_SPEED && speed<=MAX_SPEED); }
        // Method to be provided by sub class.
        virtual void setSpeed(int8_t speed) =0;
};

#ifdef SERVO_DRV_EN
/**
 * Subclass of Wheel() to represent a Continues Rotation Servo (CRS).
 **/
class Wheel_CRS : public Wheel {;
    private:
        // The pin the servo is connected to. This must be a pin supported by
        // the Arduino standard Servo library. It seems that the latest Arduino
        // code supports any digital pin.
        uint8_t pin;
        // A Servo object for controlling the servo
        Servo servo;

    public:
        Wheel_CRS(uint8_t p, int8_t sd, bool inv=false);
        void setSpeed(int8_t speed);
};
#endif // SERVO_DRV_EN

#ifdef HBRIDGE_DRV_EN
/**
 * Subclass of Wheel() to represent a Brushed DC Motor (BDM) driven via an
 * HBridge.
 *
 * NOTE: The HBridge *never* be driven with both forward and reverse pins on,
 *       even if the HBridge was designed to handle this. Doing so with most
 *       HBridges is a sure way to overload and destroy the driver transistors.
 **/
class Wheel_HB : public Wheel {
    private:
        // The pin to set high to drive the motor forward. If using the SoftPWM
        // library for PWM output (HBRIDGE_SOFT_PWM is defined), then any
        // digital pin can be used, else for hardware supported PWM, only pins
        // with PWM output may be used.
        uint8_t pinFwd;
        // The pin to set high to drive the motor reversed. The same PWM pin
        // considerations applies as for pinFwd.
        uint8_t pinRev;

    public:
        Wheel_HB(uint8_t pinF, uint8_t pinR, int8_t sd, bool inv=false);
        void setSpeed(int8_t speed);
};
#endif // HBRIDGE_DRV_EN

/**
 * Class that combines wheels into a single drive train control
 **/
class DriveTrain : public Task {
    private:
        // Pointer to external command store from which to fetch any new
        // movement commands to execute.
        uint8_t *commandStore;

#ifdef HBRIDGE_DRV_EN
        Wheel_HB *wheel[2];    // Left and Right wheels for HBrige drivers
        uint32_t powerStartTimer; // Time to end powerstart mode
#else
        Wheel_CRS *wheel[2];  // Left and Right wheels for Continues Servo Drivers
#endif // HBRIDGE_DRV_EN
        int8_t speed;        // Current relative speed as percentage of full speed
        int8_t dir;          // Direction of travel, -100 to 100. See MovementControl docs.

        /**
         * Update the wheels speed based on the current direction and speed.
         **/
        void updateWheels(); // Updates the wheel rotation from speed and dir.

    public:
#ifdef HBRIDGE_DRV_EN
        /**
         * Sets up a drive train for HBridge controlled motors.
         *
         * @param cs: Pointer to external command store to check for new commands.
         * @param pinLeftF: Left HBridge forward pin
         * @param pinLeftR: Left HBridge reverse pin
         * @param pinRightF: Right HBridge forward pin
         * @param pinRightF: Right HBridge reverse pin
         * @param leftInv: Set to true to invert left motor rotation direction
         * @param rightInv: Set to true to invert right motor rotation direction
         **/
        DriveTrain(uint8_t *cs, uint8_t pinLeftF, uint8_t pinLeftR,
                   uint8_t pinRightF, uint8_t pinRightR,
                   bool leftInv=false, bool rightInv=false);
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

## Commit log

2017-09-07 Add low level wheel control
    The WheelXXX classes are used to control a rotation direction and speed
    of a single wheel. The wheel can be driven by a Continues Rotation Servo
    or be a Brushed DC Motor driven via an HBRidge.
    The Wheel object abstracts the rotation control such that the actual
    drive mechanism is irrelevant.
    Speed is managed as a percentage of full speed, i.e. a speed value of
    100% is full speed in the forward direction, 0% is stopped and -100% is
    full speed in the reverse direction.
    Forward and reverse mechanical rotation is determined by the hardware
    connections, pin assignments (in case of HBridge) and side of the robot
    the wheel is attached to.
    Rotation direction can also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
    [config.h, driveTrain.cpp, driveTrain.h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]
2017-09-10 Add movement control via the DriveTrain class.
    The DriveTrain combines two wheels into on drive train, allowing moving
    and turning of the robot.
    Include visuals to illustrate control of movement w.r.t. speed and
    direction settings.
    Add tests to test drive train functionality.
    Update documentation with details about the drive train and movement
    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
    [MovementControl.ods]
2017-09-12 First test of Cybot firmware
    This is the first test of combining the various modules into one sketch
    to create the Cybot firmware.
    The DriveTrain was changed to make it a Task which will check for any new
    commands that it needs to action, and issue the required changes to the
    Wheels.
    Some minor comment changes is to start bringing Class, method and
    function comments into the headers files instead of the code files. The
    argument is that more often I would look in the header file for usage
    information than in the code file. We'll see how this goes.
    [commands.cpp, config.h, cybot.ino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]
2017-09-15 Speed/Direction feedback over Bluetooth. Control improvement. Bug fixes.
    * Add an option to feed speed and direction values back to Bluetooth
    controller in DriveTrain if the BT_FEEDBACK option is enabled in
    config.h
    * Control improvements to give a more natural control experience:
    * The forward command will now set the direction to 0 and make sure
    the speed is set for forward (positive) at the current speed.
    * The reverse command will also set the direction to 0 (direct
    forward), but will force the speed in te reverse direction at the
    current speed. This makes the reverse command more intuitive now.
    * When going forwards or reverse from standstill, the speed is forced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
    [commands.cpp, config.h, control.cpp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]
2017-09-15 Add optional power start function for DC motors.
    Using PWM speed control for a DC motor makes getting the motor into
    motion at slow speeds a bit difficult at times. The power start
    functionality allows for a DC motor put into motion from stand still, to
    be ramped up to full power to start the motion, and then tapering the
    speed down to the desired start speed over a short period of time
    (milliseconds, normally).
    [config.h, driveTrain.cpp, driveTrain.h]
2017-09-20 Fix Serial and BT learn modes to use Serial output and not debug marco.
    [commands.cpp, control.cpp]
2017-09-30 Add global shared space. Fix slice hogging by DriveTrain task.
    * Add a global data structure consiting of variables for holding various
    state information. This structure is globally available by any module
    that includes config.h and allows easy, but structured sharing of
    global data between modules and tasks.
    * Fix the canRun() method of DriveTrain so that it only runs for new
    commands in can hanlde. The way that the TaskSchedular works, is that
    everytime a task is run (it's run() method called), it will resstart
    the scheduling from the first task in the list. Due to the
    DriveTrain.canRun() method previously always allowed the task to be
    run unless there is no new command, it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
    [config.h, cybot.ino, driveTrain.cpp]
2017-10-05 Add support for 128x64 SSD1306 type OLED over I2C.
    First phase support for adding a display. Only the OLED display above is
    supported for now.
2017-10-05 First add of some schematics in KiCAD format.
    These are a bit of a jumble of some of the Cybot schematics reproduced,
    and then the start of schematics for re-using the current hardware with
    an Arduino.
    Still a work in progress.
    [LightIO.kicad_pcb, LightIO.sch, Motor+PowerBoard.kicad_pcb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]
